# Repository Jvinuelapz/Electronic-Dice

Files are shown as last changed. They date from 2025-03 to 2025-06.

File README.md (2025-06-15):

# Electronic Dice with ATmega328P

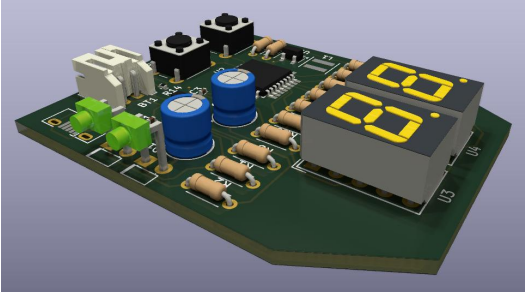
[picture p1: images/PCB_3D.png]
3D Visualization of the PCB Design


This repository documents a complete engineering design cycle for a multi-sided electronic dice. The project covers the entire development process, from initial problem definition and component research to detailed schematic design, PCB layout, software development, and 3D enclosure modeling. While a physical prototype was not assembled, all engineering stages for a production-ready device were completed.

The final design is a compact, key-fob-sized device featuring a rechargeable LiPo battery, USB-C charging, and a dual 7-segment display.

📄 **[Read the full project report (PDF)](Development%20Process.pdf)**

---

## ✨ Key Features

* **Multi-Sided Dice:** Supports d4, d6, d8, d10, d12, and d20 dice types, selectable via a tactile button.
* **Compact Design:** The final PCB measures just 38 x 48 mm.
* **Clear Display:** Utilizes two 7-segment displays with multiplexing to clearly show roll results.
* **Rechargeable:** Powered by a 150mAh LiPo battery with on-board USB charging via a TP4057 IC.
* **Power Management:** Includes an LM2731 step-up voltage regulator to provide a stable 5V supply to all components.

---

## ⚙️ The Engineering Process

This project followed a structured engineering lifecycle to ensure all objectives were met efficiently and reliably.

1. **Problem Definition:** Defined client requirements, project objectives, and created a Gantt chart for project planning.

2. **Research & Feasibility:** Analyzed existing products and sourced compatible, cost-effective components (ATmega328P, 7-segment displays, etc.). A full feasibility assessment (Technical, Economic, Operational) was conducted.

3. **Concept Design:**
   
    * **Software:** Developed the logic flow, including dice type selection, random number generation, and display multiplexing.
    * **Hardware:** Created a detailed schematic, outlining power management, microcontroller connections, and user interface components.

4. **PCB & Enclosure Design:**

    * Designed a compact, two-layer PCB using KiCad, optimized for size and signal integrity.
    * Modeled a custom 3D-printable enclosure in Autodesk Fusion 360 to house all components securely.

5. **Simulation & Validation:** The core logic was tested in a simulated breadboard environment to validate the software and hardware interaction before finalization.

---

# 🚀 Core Competencies

* **Embedded Systems Programming:** C++ development for the ATmega328P microcontroller using the Arduino IDE.
* **PCB Design & Layout:** Schematic capture and two-layer PCB design using KiCad.
* **Hardware Design:** Component selection, power management design (charging, voltage regulation), and circuit simulation.
* **3D Modeling:** Designing a functional and ergonomic enclosure for 3D printing using Autodesk Fusion 360.
* **Project Management:** Following a structured engineering design cycle from concept to a production-ready design.

---

# 🔧 Technical Specifications

* **Microcontroller:** ATmega328P-AU
* **Display:** 2x HDSP-513A Common Cathode 7-Segment Displays
* **Power:** 3.7V 150mAh LiPo Battery
* **Charging:** TP4057 Charging IC with Micro-USB input
* **Voltage Regulator:** LM2731 Step-Up Converter (outputting 5V)
* **User Input:** 2x Tactile Switches (for dice type and roll)

---

## 🗂️ Repository Structure

- `/code`: Contains the Arduino `.ino` sketch for the microcontroller.
- `/Hardware`: Includes the source files for the PCB layout (`/PCB`)and the 3D model for the enclosure (`/3D_Model`).
- `/Images`: Contains visual assets for this README.
- `Development_Process.pdf`: The detailed logbook documenting the entire project.

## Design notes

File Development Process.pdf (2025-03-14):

## Engineering Cycle, Mixed Signal Processing and PCB

## Design

Task 1: Define the problem statement

Firstly, read the background above and understand what the client wants you to develop.

List all the objectives related to the problem statement and develop a Gantt Chart to

show how long this project might take to complete.

Alex, a board game enthusiast, desires a compact device that can function as a multi-

sided dice generator. This device should meet the following key objectives:

- Compact size: No larger than 70mm x 50mm.
- Multi-dice Functionality: Dice types d4, d6, d8, d10, d12 and d20.
- Visual display: Reveals the result of each roll.
- True randomness
- User-friendly interface: A button to switch between dice types.
- Extended battery life

Based on the objectives, here’s a Gantt Chart for the estimated timeline of the project.

Activity | Week 1 | Week 2 | Week 3
Define the problem statement
Research and analysis
Brainstorming
Concept Development – Hardware
Concept Development – Software
Feasibility Assessment
Detailed Design and Planning – Schematic Design Detailed Design and Planning – PCB Design Detailed Design and Planning – Material and Resource Planning

Field Ready Prototype and Testing and Evaluation Optimization and Improvement
Design a 3D model case for the product
Table 1. Electronic Dice Project's Gantt Chart

Task 2: Research and analysis

Look at existing products and approved sellers to find which parts you need to make this client project. Make an Equipment table that follows this structure, please add more columns if needed.

For this task, I focused on identifying the components needed to design and build the product. I researched existing products and suppliers to find parts that met the project requirements, considering cost, availability, and compatibility. The goal was to ensure the components are efficient, compact, and aligned with the client's needs.

Component Research and Justification

The table below summarizes the key components I considered initially and the rationale

behind their selection:

Supplier and Cost Overview

I sourced the components from approved suppliers like Mouser Electronics, Digi-Key,

and Model Rockets to ensure high quality and reliability. The table below shows the

details of the selected components, including cost, quantity, and manufacturer. Here are

key observations from the initial list of components needed.

Table 2. Initially Needed Components List

1. Total Cost

The total cost of the main components is approximately £18, including VAT but not

including shipping, which fits within a reasonable budget for prototyping.

2. Suppliers and Reliability

Most components were sourced from Mouser Electronics, with the battery sourced

from Model Rockets. All suppliers are reputable, ensuring reliable components and

availability.

3. Compatibility

All components are compatible with the 3.3V–5V operating range of the system. For

example, the LiPo battery and step-up voltage regulator ensure that the

microcontroller and display receive stable power.

Observations and Challenges

- Component Size: The compact size of components like the ATMEGA328P-AU

and the 7-segment display ensures that the project can meet the size constraint.

Product NameProduct Description URL | Distributor | Manufacturer Cost (inv VAT)Quantity | | | Total
ATMEGA328P-AU8-bit Microcontrollers - MCU 32KB In-system Flash 20MHz 1.8V-5.5V https://www.mouser.co.uk/ProductDetail/Microchip-Technology/ATMEGA328P-AU?qs=K8BHR703ZXiCmmgp6%2FGNmQ%3D%3D Mouser Electronics Mrochip | | | £2.10 | 1 | £2.10
7-segment (HDSP-513A) LED Displays & Accessories Red 643nm 0.56in 7 Segment https://www.mouser.co.uk/ProductDetail/Broadcom-Avago/HDSP-513A?qs=pQfy5%252BKCabIcw5BGtxIW9w%3D%3D Mouser Electronics Broadcom Limited | | | £1.55 | 2 | £3.10
Tactile Switch (PHAP3344R) Tactile Switches TACT SWITCH PCB MOUNT https://www.mouser.co.uk/ProductDetail/Apem/PHAP3344R?qs=HFfMDpzxxd0eFvDypKImNg%3D%3D Mouser Electronics Apem | | | £0.32 | 2 | £0.64
Usb B Micro (USB3080-30-00-A) USB Connectors Micro B Skt, Bottom-SMT, R/A, 30u" NoPeg, W/shell stake, T&R https://www.mouser.co.uk/ProductDetail/GCT/USB3080-30-00-A?qs=KUoIvG%2F9IlZDMJJTQkXE0A%3D%3D Mouser Electronics GCT | | | £0.56 | 1 | £0.56
Lipo Battery (M105318) 3.7V 150mAh LiPo battery. https://modelrockets.co.uk/ground-equipment/batteries/150mah-3-7v-lipo-battery-2-pin-jst-connector/ Model RocketsPKCell | | | £8.75 | 1 | £8.75
Step-Up Voltage Regulator (LM2731YMF) Switching Voltage Regulators 0.6/1.6 MHz Boost Converters With 22V Internal FET Switch in SOT-23 5-SOT-23 -40 to 125 https://www.mouser.co.uk/ProductDetail/Texas-Instruments/LM2731YMF?qs=X1J7HmVL2ZEEUACYDb9YJg%3D%3D Mouser Electronics Texas Instruments | | | £3.02 | 1 | £3.02

- Power Efficiency: I selected a LiPo battery from Model Rockets and a voltage

regulator to optimize the dice for extended use, ensuring low power consumption,

while the system is portable.

- Cost vs. Quality: While some cheaper alternatives were available, I prioritized

components with a proven track record to avoid issues during prototyping.

Task 3: Brainstorming

For the microcontroller, there were a few options on the table. Initially, we thought about

using an Arduino UNO, given its familiarity and ease of use. However, its size was a

drawback for this project. We also considered the ATtiny85, which is compact but has

only 3 pins, limiting the number of components it could support. The ATtiny84 offered

more pins (12), but we felt it still might be too restrictive for the design’s complexity.

Finally, we chose the ATmega328P, a small and compact device, yet it offers enough

I/O pins to handle all the necessary components without compromising functionality.

Next, we discussed the power supply. Since the device needs to be portable, we quickly

dismissed the idea of using a standard 9V battery, which would be bulky and require

frequent replacements. Instead, we opted for a rechargeable LiPo battery. To make

recharging easy, we decided to integrate a USB-B micro connector for charging,

ensuring that the device could be conveniently powered up without needing external

chargers or frequent battery replacements.

For the display, the main challenge was finding something that would clearly show the

numbers without consuming too much power or requiring too many pins. Initially, we

investigated using an OLED or e-ink display, but these would require more complex

programming and higher power consumption than necessary. We settled on two 7-

segment displays because we could use multiplexing, which would allow us to control

both displays with fewer pins, further optimizing the design.

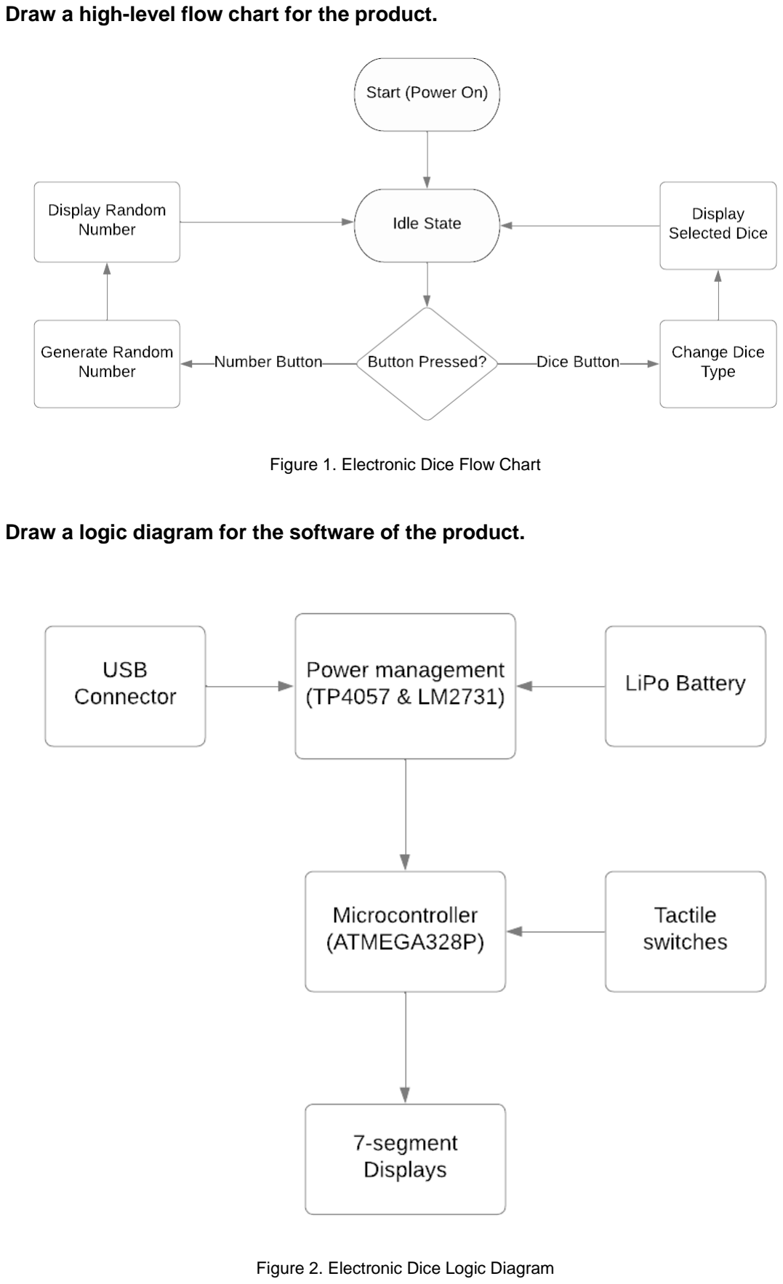
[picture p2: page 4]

Draw a high-level flow chart for the product.

Figure 1. Electronic Dice Flow Chart

Draw a logic diagram for the software of the product.

Figure 2. Electronic Dice Logic Diagram

Task 4: Concept Development – Hardware

The initial hardware prototype for the project involves using an Arduino UNO, which

incorporates the ATmega328P microcontroller, along with two buttons and two 7-

segment displays to visualize the results. The system simulates a dice rolling mechanism

with multiple dice types (d4, d6, d8, d10, d12, and d20). Here's a breakdown of how the

hardware is connected:

- Buttons: The first button is used to switch between different dice types (d4, d6,

etc.). Each press cycles through the different dice options and shows on the

display the selected dice. The second button is responsible for generating a

random number within the selected dice range.

- 7-Segment Displays: The output is visualized on two 7-segment displays, which

are used to show the dice result. The segments (A-G) of both 7-segment displays

are wired together to the same GPIO pins of the ATmega328P.

The cathodes of the two displays are connected to separate GPIO pins on the

microcontroller. This allows for multiplexing, where each display can be controlled

individually by activating its corresponding cathode while turning off the other display.

This way, we can display different numbers on each display despite sharing the segment

connections.

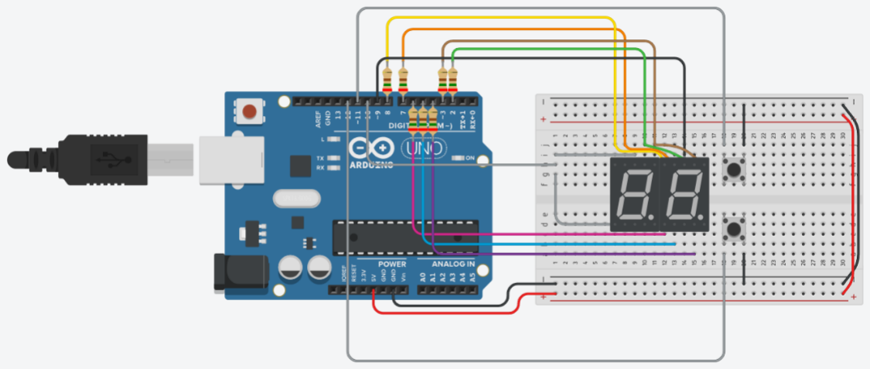
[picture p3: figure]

Figure 3. Electronic Dice Hardware Concept

Task 5: Concept Development – Software

Once the main hardware concept was outlined, including the microcontroller, buttons,

and displays, the next step was to integrate the corresponding software. The software is

tightly coupled with the hardware, ensuring that all components work seamlessly

together to achieve the intended functionality. The code controls the dice rolling system, manages user inputs, and displays the results in real time on two 7-segment displays.

Here’s a breakdown of the code and how it functions:

1. Pin Assignments:
- Pins pinA through pinG control the segments of the 7-segment display

(common across both displays).

- display1Pin and display2Pin are used for multiplexing between the two

displays, allowing each digit to be shown one at a time.

- buttonDiceType is for selecting the type of dice, and buttonRoll triggers the

roll to generate a new random number.

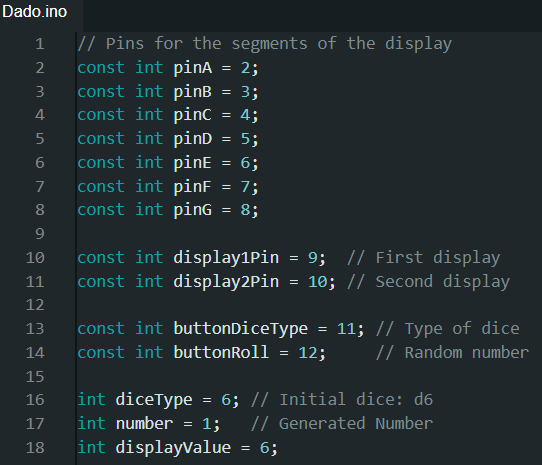
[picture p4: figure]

Figure 4. Electronic Dice Initialization

2. Initial Variables and Constants:
- diceType starts at 6, representing a d6 dice by default.
- displayValue stores the number currently displayed on the displays.
- digitSegments array holds the binary encoding for each digit to control which

segments are turned on for each number.

3. Setup Function:
- Configures segment pins and display control pins as outputs.
- Sets up buttons with INPUT_PULLUP mode, enabling internal pull-up

resistors.

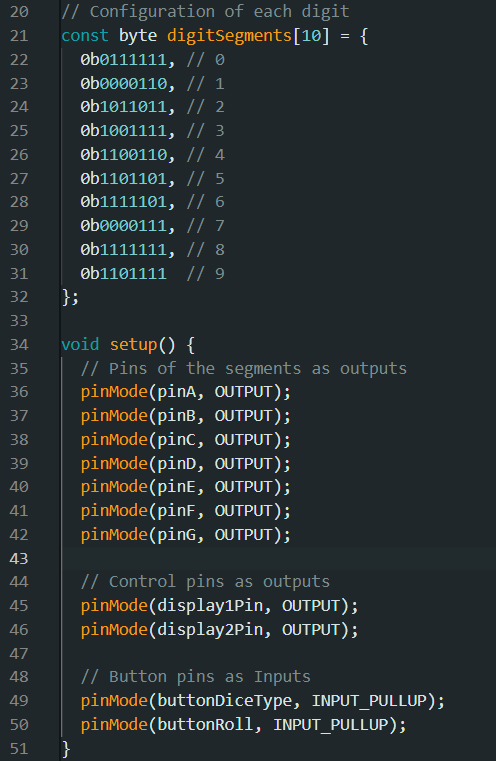
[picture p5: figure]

Figure 5. Electronic Dice Setup Function

4. Loop Function:
- When buttonDiceType is pressed, it calls changeDiceType function to cycle

through different dice types (d4, d6, d8, d10, d12, and d20).

- When buttonRoll is pressed, it calls rollDice function to generate a random

number within the current dice range.

- After handling button inputs, the displayNumber(displayValue); function is

called to show the current number on the 7-segment displays with

multiplexing.

5. Dice Type Switching (changeDiceType):
- It cycles through the dice types in this order: d4 → d6 → d8 → d10 → d12 →

d20, then back to d4.

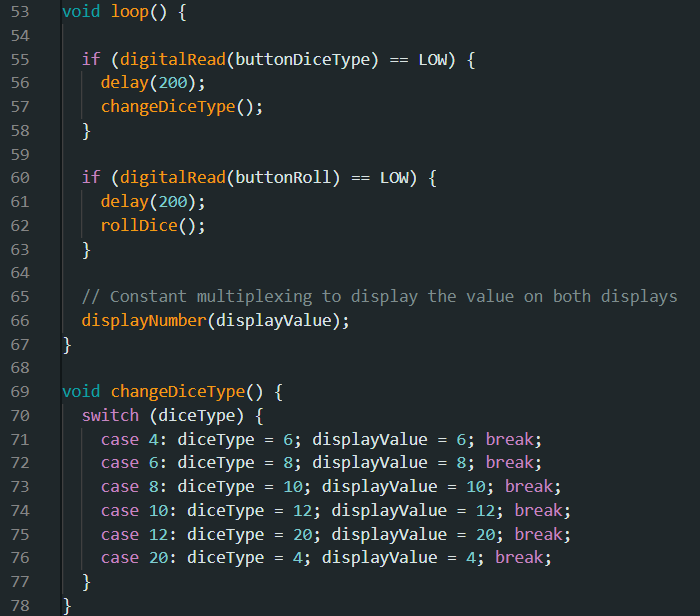
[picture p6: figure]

Figure 6. Electronic Dice Loop Function

6. Dice Rolling (rollDice):
- It generates a random number between 1 and the maximum value of the

selected dice type and stores it on the DisplayValue variable.

7. Displaying the Number (displayNumber):
- This function splits the number into tens and units.
- Each digit is displayed on its respective display using multiplexing, with a brief

delay to switch between digits smoothly.

8. Setting Segments (setSegments):
- This function uses bitwise operations to activate the correct segments for a

given digit by controlling each segment pin.

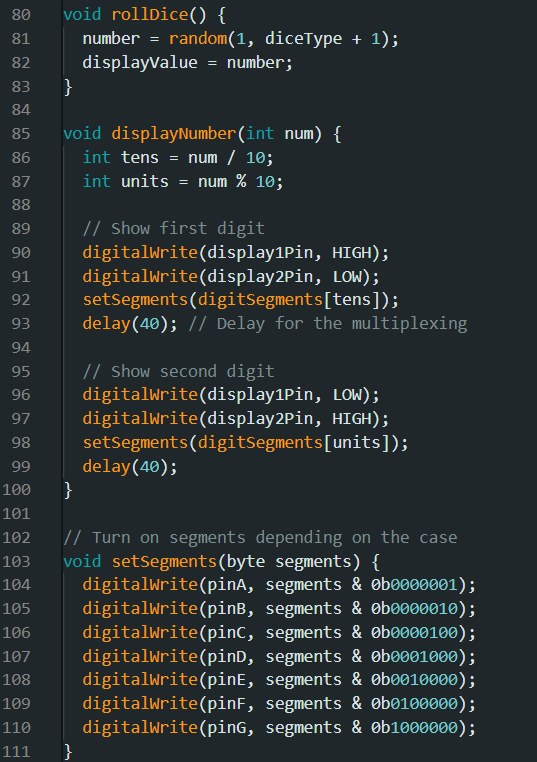
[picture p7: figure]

Figure 7. Electronic Dice RollDice Function

Task 6: Feasibility Assessment

In this task, I evaluated the technical, economic, and operational feasibility of the product

design, by analysing the finalized component selection, costs, and compatibility. This

way, I ensured that the design aligns with the project’s constraints and objectives.

Below is the finalized table of components, including their descriptions, suppliers, costs,

and quantities:

Table 3. Final List of Components

Technical Feasibility

The selected components meet the design’s technical requirements and are compatible

with each other to achieve the functionality of the product. Below is a detailed analysis

of how each component contributes to the system:

1. Core Components
- Microcontroller (ATMEGA328P-AU): It provides sufficient GPIOs to control

the two displays and reads inputs from the tactile buttons, while it supports

low-power operation.

- 7-segment displays (HDSP-513A): The use of two of these components

creates a compact two-digit display for showing dice roll results clearly.

Efficient power consumption and compatible with the regulated 5V supply.

2. Input Components
- Tactile Switches (PHA3344R): Two buttons necessary, one for cycling

through dice types and one for generating the random number. I selected

Single Pole Single Throw (SPST) switches, which ensure reliable user input

with robust tactile feedback.

3. Power Management Components
- LiPo Battery (3.7V, 150mAh): Compact and lightweight battery chosen

mainly to meet the device’s portability requirements, while providing sufficient

capacity for prolonged usage, powering the microcontroller, displays and

peripheral components. Additionally, the selected battery includes a built-in

security circuit, ensuring it never truly powers off, thus protecting the device

from abrupt power loss and preserving system stability during usage.

Product Name | Product Description URL | Distributor | Manufacturer | Cost (inv VAT) Quantity | | Total
ATMEGA328P-AU | 8-bit Microcontrollers - MCU 32KB In-system Flash 20MHz 1.8V-5.5V https://www.mouser.co.uk/ProductDetail/Microchip-Technology/ATMEGA328P-AU?qs=K8BHR703ZXiCmmgp6%2FGNmQ%3D%3D Mouser Electronics | | Microchip | £2.10 | 1 | £2.10
7-segment (HDSP-513A) | LED Displays & Accessories Red 643nm 0.56in 7 Segment https://www.mouser.co.uk/ProductDetail/Broadcom-Avago/HDSP-513A?qs=pQfy5%252BKCabIcw5BGtxIW9w%3D%3D Mouser Electronics | | Broadcom Limited | £1.55 | 2 | £3.10
250R Resistor (OK15G5E-R52) | Carbon Film Resistors - Through Hole 1.5 Ohm 1/4W 5% 250 Volt https://www.mouser.co.uk/ProductDetail/Ohmite/OK15G5E-R52?qs=AkUtuiJmyfmB5P4Zp1aBYw%3D%3D Mouser Electronics | | Ohmite | £0.09 | 7 | £0.63
Tactile Switch (PHAP3344R) | Tactile Switches TACT SWITCH PCB MOUNT https://www.mouser.co.uk/ProductDetail/Apem/PHAP3344R?qs=HFfMDpzxxd0eFvDypKImNg%3D%3D Mouser Electronics | | Apem | £0.32 | 2 | £0.64
TP4057 | SOT23-6 BATTERY MANAGEMENT ICS R https://www.digikey.co.uk/en/products/detail/umw/TP4057/17635237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 DigiKey | | UMW | £0.42 | 1 | £0.42
Usb B Micro (USB3080-30-00-A)USB Connectors Micro B Skt, Bottom-SMT, R/A, 30u" NoPeg, W/shell stake, T&R https://www.mouser.co.uk/ProductDetail/GCT/USB3080-30-00-A?qs=KUoIvG%2F9IlZDMJJTQkXE0A%3D%3D Mouser Electronics | | | GCT | £0.56 | 1 | £0.56
JST-PH 2 Pin Connector (B2B-PH-K-S) CONN HEADER VERT 2POS 2MM https://digikey.co.uk/en/products/detail/jst-sales-america-inc./B2B-PH-K-S/926611?productid=926611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 DigiKey | | | JST Sales America Inc. | £0.16 | 1 | £0.16
Led Charging (TLPR5600) | LED RED DIFF SIDE VIEW T/H R/A https://www.digikey.co.uk/en/products/detail/vishay-semiconductor-opto-division/TLPR5600/4074661 DigiKey | | Vishay Semiconductor Opto Division£0.60 | | 1 | £0.60
Led Charged (TLPG5600) | LED GREEN DIFF SIDE VIEW T/H R/A https://www.digikey.co.uk/en/products/detail/vishay-semiconductor-opto-division/TLPG5600/4074658 DigiKey | | Vishay Semiconductor Opto Division£0.60 | | 1 | £0.60
Ceramic Capacitor (CL05B103JB5NNND) CAP CER 0.1UF 50V X7R 0402 https://www.digikey.co.uk/en/products/detail/samsung-electro-mechanics/cl05b103jb5nnnd/3894195 DigiKey | | | Samsung Electro-Mechanics | £0.10 | 2 | £0.20
Electrolitic Capacitor (865080642006) CAP ALUM 10UF 20% 50V SMD https://www.digikey.co.uk/en/products/detail/w%C3%BCrth-elektronik/865080642006/5728046 DigiKey | | | Würth Elektronik | £0.18 | 2 | £0.36
1k Resistor (CF1/2CT52R102J) | RES 1K OHM 5% 1/2W AXIAL https://www.digikey.co.uk/en/products/detail/koa-speer-electronics-inc/cf1-2ct52r102j/13537515 DigiKey | | KOA Speer Electronics, Inc. | £0.11 | 2 | £0.22
2k Resistor (CF1/4CT52R202J) | RES 2K OHM 5% 1/4W AXIAL https://www.digikey.co.uk/en/products/detail/koa-speer-electronics-inc/cf1-4ct52r202j/13537624 DigiKey | | KOA Speer Electronics, Inc. | £0.09 | 2 | £0.18
Lipo Battery (M105318) | 3.7V 150mAh LiPo battery. https://modelrockets.co.uk/ground-equipment/batteries/150mah-3-7v-lipo-battery-2-pin-jst-connector/ Model Rockets | | PKCell | £8.75 | 1 | £8.75
Step-Up Voltage Regulator (LM2731YMF) Switching Voltage Regulators 0.6/1.6 MHz Boost Converters With 22V Internal FET Switch in SOT-23 5-SOT-23 -40 to 125 https://www.mouser.co.uk/ProductDetail/Texas-Instruments/LM2731YMF?qs=X1J7HmVL2ZEEUACYDb9YJg%3D%3D Mouser Electronics | | | Texas Instruments | £3.02 | 1 | £3.02
1.2k Resistor (CFM12JT1K20) | RES 1.2K OHM 5% 1/2W AXIAL https://www.digikey.co.uk/en/products/detail/stackpole-electronics-inc/CFM12JT1K20/1741836 DigiKey | | Stackpole Electronics Inc | £0.08 | 1 | £0.08
3.9k Resistor (CF14JT3K90) | RES 3.9K OHM 5% 1/4W AXIAL https://www.digikey.co.uk/en/products/detail/stackpole-electronics-inc/CF14JT3K90/1741386 DigiKey | | Stackpole Electronics Inc | £0.08 | 1 | £0.08
SMD Power inductor (SRR1210-100M) Power Inductors - SMD 10uH 20% SMD 1210 https://www.mouser.co.uk/ProductDetail/Bourns/SRR1210-100M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 Mouser Electronics | | | Bourns | £0.96 | 1 | £0.96
10k Resistor (MCT0603MD1052BP500) Thin Film Resistors - SMD MCT 0603-25 0.1% AT P5 10K5 https://www.mouser.co.uk/ProductDetail/Vishay-Beyschlag/MCT0603MD1052BP500?qs=17u8i%2FzlE883pCG3RQV5%2Fw%3D%3D Mouser Electronics | | | Vishay / Beyschlag | £0.34 | 2 | £0.68
| | | | | Total | £23.34

- Step-Up Voltage Regulator (LM2731YMF): Boosts the 3.7V output of the

battery to 5V, ensuring stable voltage for all the components in the product,

while it efficiently regulates power to avoid unnecessary losses and extending

battery life.

- Battery Charging IC (TP4057): Allows recharging the LiPo battery via a

micro-USB connector, ensuring safe charging with built-in overcharge

protection.

- Capacitors
- Ceramic Capacitors (0.1µF): Used for decoupling to stabilize voltage

and filter noise in the power supply, ensuring smooth operation of the

microcontroller and display.

- Electrolytic Capacitors (10µF): Provide additional power stability,

particularly for the voltage regulator during periods of higher current

draw.

4. Passive Components
- 250Ω Resistors: Current-limiting resistors for the 7-segment displays,

ensuring that LEDs are not overdriven.

- 1kΩ and 3.9kΩ Resistors: Pulldown or pullup resistors for tactile switches to

ensure stable signal readings from the buttons.

5. Connectivity Components
- Micro-USB Connector: Robust and compact design that allows the device

to be charged conveniently using standard USB power sources,

- JST Connector: Provides secure and compact connections for the battery,

making assembly and maintenance easier.

6. Additional Considerations
- Multiplexing for 7-segment Displays: By multiplexing (the microcontroller

alternates between the tens and units digits quickly enough to make it appear

as though both digits are displayed at the same time) the two displays, I

successfully reduced the number of GPIO pins needed to control the

segments.

- Size Constraints: The use of compact components such us the

microcontroller or the battery fit in the key-fob-sized requirements.

Additionally, SMD versions of passive components further minimize the

overall PCB size.

The selected components are expected to operate seamlessly together under the

specified voltage conditions (5V, which preventing flickering or glitches). With this

efficient power management, the device is projected to offer extended usage on single

charge while maintaining functionality.

Economic Feasibility

This assessment is evaluated based on the total cost of components, sourcing reliability,

production scalability, and the cost-benefit considerations of design decisions. Below is

an in-depth analysis of the cost and financial implications of the project:

1. Component Cost Analysis
- The total cost of components, including VAT, is £22.63 for a single unit. This

cost is reasonable for a prototyping phase where parts are sourced

individually and not in bulk (Shipping not included).

2. Bulk Production Potential
- Savings in Bulk Orders: Many components can be purchased at

significantly reduced prices when ordered in bulk, like passive components or

microcontrollers. A rough estimate shows that bulk purchasing could

decrease the component cost per unit by 20-30%, bringing the cost closer to

£16 per unit in a hypothetical larger scale production.

- Scalability: By transitioning to Surface Mount Devices (SMD) for passive

components, assembly time and labour costs can be reduced in large scale

manufacturing. A single PCB design can accommodate all components for

automated assembly, which lowers production costs.

- Value vs. Cost: In the prototype stage, £22.63 per unit is justified by the need

for high-quality components to ensure functionality during testing. Moreover,

the ability to recharge the device adds value to the design, avoiding the

recurring cost of disposable batteries. On the other hand, for a retail product

it would be essential to find cost reduction strategies to achieve a profitable

margin while keeping the final product affordable.

3. Challenges
- Initial Cost for Prototyping: Prototyping often incurs higher costs due to the

lack of economies of scale.

- Logistics: The need to source the components from multiple suppliers

increases the shipping costs and complexity. Consolidating suppliers or

sourcing locally could benefit the overall cost

4. Future Cost Optimization
- Component Consolidation: Explore integrated IC solutions that combine

microcontroller, power management, and charging capabilities to reduce the

total component count and cost.

- Supplier Negotiations: Negotiate with suppliers for better pricing when

ordering in bulk.

The project is economically feasible for prototyping and offers significant potential for

cost reduction in bulk production. By balancing quality, functionality, and affordability, the

design ensures a competitive product with a strong value proposition. Future cost

optimization strategies will further enhance its viability for commercial production.

Operational Feasibility

The operational feasibility of the product focuses on the ease of assembly, user

functionality, portability, and maintainability. Below is a detailed analysis of how the

design meets these operational objectives:

1. Ease of Assembly
- Component Placement: The use of through-hole components, like the tactile

switches and resistors, simplifies prototyping and assembly during the initial

design stage. However, for larger scale production it would be necessary to

transition to SMD components. A well-optimized PCB design ensures that

components are logically and efficiently placed, minimizing assembly errors.

- Modular Design: Critical parts, such as the battery or the USB connector,

are easily replaceable, which ensures straightforward repairs or upgrades if

needed. Additionally, the use of a JST connector allows for simple

disconnection and reconnection without soldering, if needed.

2. User Functionality
- Dice Rolling Process: The design provides a simple and intuitive interface

by using only two buttons, one for selecting the dice and the other for rolling

it. The user sees the both the selected dice and the generated number on the

7-segments displays, with multiplexing ensuring smooth digit transitions.

- Multi-Dice Compatibility: The device supports multiple dice types, as

required by the client, which increases the utility and appeal of the device.

- Portability: The compact design ensured the dice is lightweight and easy to

carry and the use of a rechargeable LiPo battery eliminates the need for disposable ones, making it more user-friendly and environmentally

sustainable.

- Display Clarity: The two displays provide bright and readable numbers even

in low-light conditions.

3. Power Efficiency
- Battery Life: The 3.7V 150mAh LiPo battery provides sufficient capacity for
extended | use, | especially | with | the | low-power | ATMEGA328P-AU

microcontroller. Efficient power management is achieved using the step-up

voltage regulator to provide a stable 5V output, ensuring all components

operate optimally without wasting energy.

- Charging Process: The TP4057 charging IC allows the device to be

conveniently recharged via a micro-USB port, ensuring ease of use and

minimizing downtime.

4. Maintainability
- Repairability: Key components like the LiPo battery and tactile switches are

modular and can be easily replaced in case of failure.

- Software Updates: The ATMEGA328P-AU can be reprogrammed via its ISP

(In-System Programming) interface, enabling software updates or bug fixes

without hardware changes.

- Component Durability: High-quality components ensure long-term

reliability.

5. Challenges and Risks
- Assembly Precision: Implementing multiplexing requires precise wiring and

logic to ensure functionality, given that errors during assembly could lead to

display glitches.

- Power Optimization: While the device is designed to efficient, real-world

testing is required to validate the expected battery life under usage patterns.

- Size Constraints: Assembling all components into the size requirements

while maintaining functionality and durability require careful PCB design and

component placement.

The design is operationally feasible, balancing ease of use, assembly simplicity, and

portability. While challenges such as size constraints and power efficiency require testing

and optimization, the design meets the project’s requirements and is well-suited for

prototyping and eventual production.

Task 7: Detailed Design and Planning – Schematic Design

The electronic dice circuit is designed to generate random dice rolls and display the

results on a dual 7-segment LED display. The design is divided into two main phases:

1. Power Management Phase: This phase handles the power input, battery

charging, and voltage regulation to ensure a stable 5V supply for the circuit. It

includes a micro-USB input, TP4057 battery charging IC, and LM2731 step-up

voltage regulator.

2. Control and Display Phase: This phase consists of the ATMEGA328P

microcontroller, tactile switches, and two 7-segment displays. The microcontroller

handles user inputs from the switches to select dice types and roll numbers. It

also manages the multiplexing and control of the 7-segment displays, ensuring

the rolled number is clearly shown to the user.

Power Management Phase

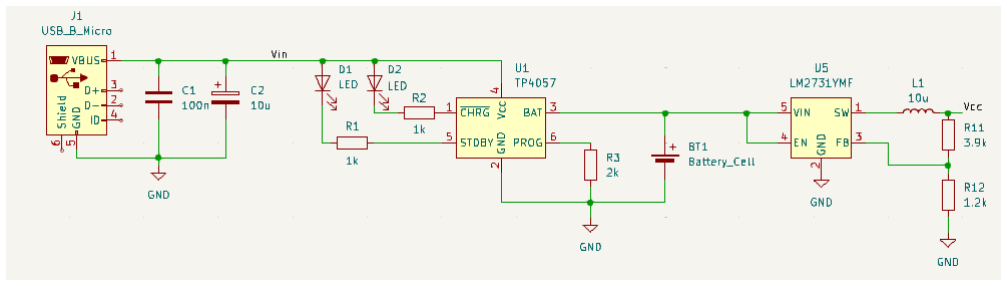
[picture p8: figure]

Figure 8. Power Management Phase Electric Scheme

In this section, the connections of each component in this phase will be explained in

detail.

1. Power Input (USB Connector)
- Component: J1 (USB_B_Micro):
- This connector provides power input to the system via a micro-USB

port.

- Pin 1 (VBUS): The power pin receives 5V from a standard USB

source.

- Pin 5 (GND): The ground connection.
- Capacitors:
- These are decoupling capacitors placed close to the USB connector

to stabilize the input voltage and filter out noise.

- C1 (100nF) handles high-frequency noise, while C2 (10µF) smooths

out low-frequency fluctuations.

2. Battery Charger TP4057 and Battery Cell
- Charger IC: TP4057 (U1):
- The TP4057 is a lithium-ion battery charging IC that ensures safe and

efficient charging of the connected battery cell.

- Pin 1 (CHRG): Connects to LED D1, which indicates charging status.
- Pin 2 (STDBY): Connects to LED D2, which indicates when the

charging is complete.

- Pin 3 (PROG): Connected to resistor R3 (2kΩ), which sets the

charging current, of approximately 500mA.

- Pin 5 (BAT): Connected to the positive terminal of the battery.
- Pin 6 (VIN): Receives the stabilized 5V from the USB input (Vin).
- Pin 4 (GND): Ground connection for the charger circuit.
- Battery Cell (BT1): A 3.7V lithium-ion battery is connected at this point,

charged by the TP4057.

3. Voltage Regulator
- Voltage Regulator IC: LM2731YMF (U5):
- This step-up voltage regulator increases the battery’s 3.7V to a stable

5V output for the rest of the circuit.

- Pin 5 (VIN): Accepts input voltage from the battery.
- Pin 1 (EN): Enable pin is tied to VIN, ensuring the regulator is always

on when the battery is connected.

- Pin 3 (FB): Feedback pin connected to a resistor divider (R11 and

R12) to set the output voltage, of 5V.

- Pin 2 (SW): The switching output is connected to an inductor (L1) to

boost the voltage.

Control and Display Phase

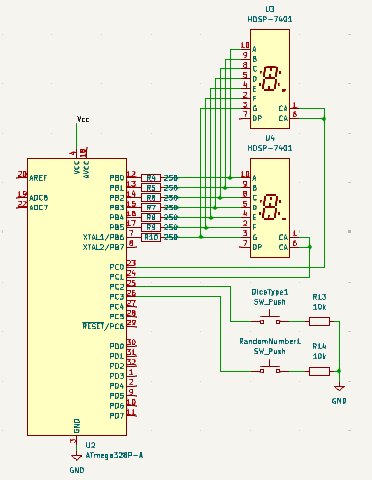
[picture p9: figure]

Figure 9. Control and Display Electric Scheme

In this section, the connections of each component in this phase will be explained in

detail.

1. Microcontroller: ATMEGA328P (U2)
- Power Supply:

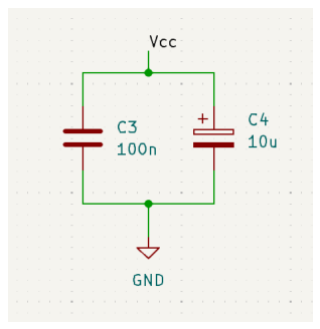
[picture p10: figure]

Figure 10. ATMEGA328P Power Supply

- Connected to Vcc with decoupling capacitors (C3 and C4) to stabilize

the power supply and filter noise.

- The ground pin (GND) is connected to the circuit's common ground.
- Connections:
- PB0–PB6 (Pins 12–18): Control the segments (A–G) of the two 7-

segment displays.

- PC0–PC1 (Pins 23, 24): Are used to multiplex the displays by

activating the common cathode of each display (U3, U4) alternately.

- PC2–PC3 (Pins 25, 26): Connected to the tactile switches for user

input.

2. Tactile Switches
- Dice Type Selection:
- Connected to PC2 of the microcontroller.
- Dice Roll Switch:
- Connected to PC3 of the microcontroller.
- Pull-Down Resistors:
- Each switch is connected to ground through pull-down resistors (R13

and R14).

3. 7-Segment Displays (U3, U4)
- Display Type:
- Common cathode displays are used for showing two-digit dice roll

results.

- Segment Control (Pins A–G):
- Each segment is connected to a GPIO pin of the microcontroller

(PB0–PB6) through current-limiting resistors (R4–R10, 250Ω each).

Task 8: Detailed Design and Planning – PCB Design

The project has reached the PCB design stage, with a finalized layout that integrates all

components and adheres to the project's compact size constraints. The PCB measures

38x48 mm, fitting the key-fob size requirement, while ensuring functionality, durability,

and manufacturability.

Final PCB (All Layers)

The image below represents the completed PCB design, showing all layers and

components. It includes:

- Front copper traces connecting components.
- Back copper traces for signal routing and ground planes.
- Placement of all components such as the microcontroller, resistors, capacitors,

LEDs, switches, and 7-segment displays.

This view provides a complete picture of how the circuit is routed, ensures optimal space

utilization within the small dimensions, and remarks the dimensions of the PCB.

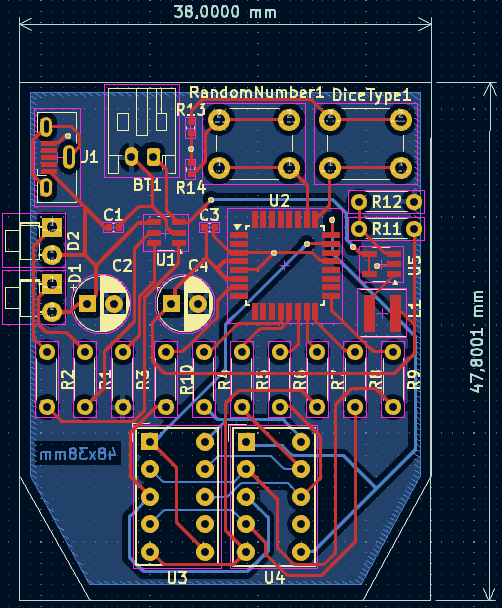
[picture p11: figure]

Figure 11. Electronic Dice PCB

Front Copper Layer

The second image highlights only the front copper layer, where most connections and

signal routing occur. This layer focuses on:

- Power distribution from the battery and voltage regulator to components.
- Critical signal traces connecting the microcontroller to the 7-segment displays

and switches.

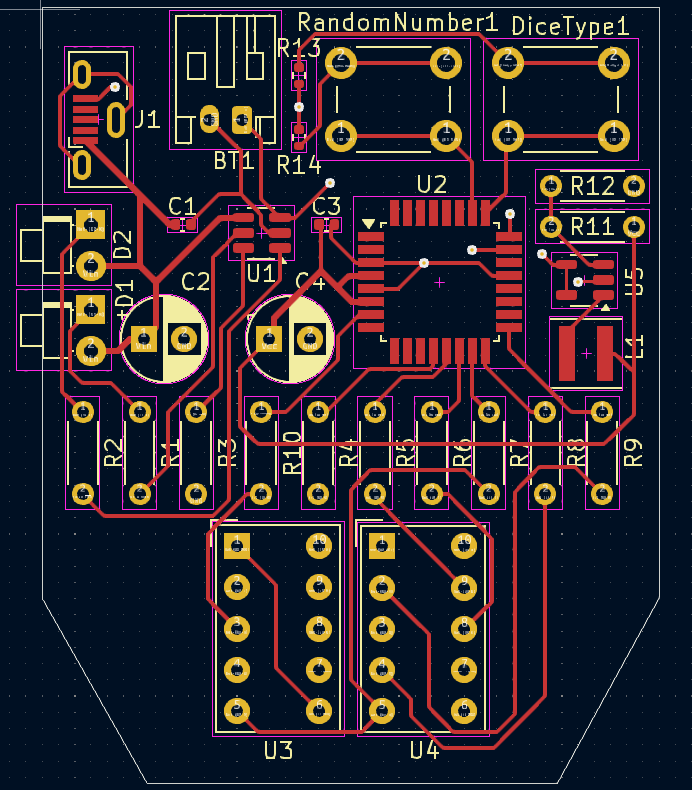
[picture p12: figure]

Figure 12. Front Copper Layer

Back Copper Layer

The third image isolates the back copper layer, primarily used for:

- Ground planes to reduce noise and stabilize the circuit.
- Supporting additional routing where space on the front layer is insufficient.

The inclusion of a back copper layer ensures a balanced and reliable PCB design, even

with compact dimensions.

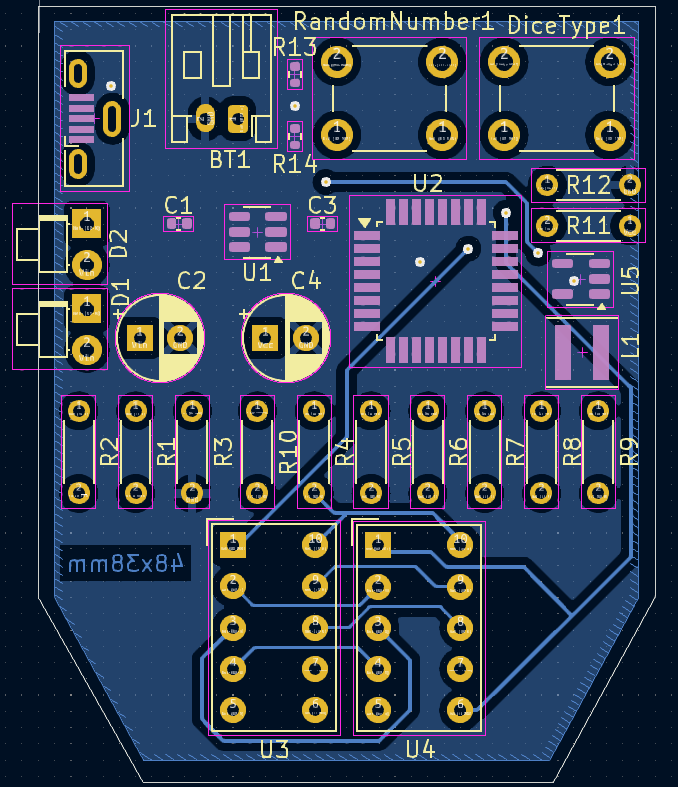
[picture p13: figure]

Figure 13. Back Copper Layer

3D View

The fourth image provides a 3D rendering of the assembled PCB, showcasing the layout

and physical placement of components. Key features include:

- Two 7-segment displays prominently positioned for clear visibility.
- Tactile switches for user input, aligned at the top for ergonomic access.
- Microcontroller and other passive components efficiently placed to minimize trace

lengths.

This visualization confirms the design's practicality and highlights the compact

arrangement within the 38x48 mm footprint.

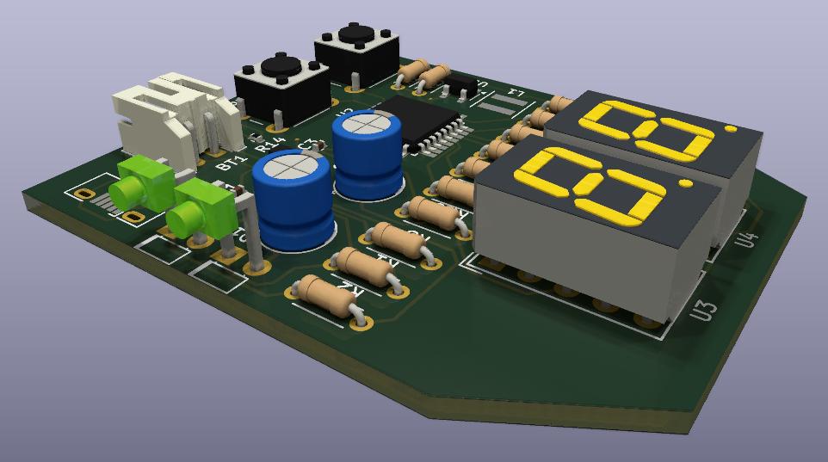
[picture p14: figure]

Figure 14. Electronic Dice PCB's 3D View

Task 9: Detailed Design and Planning – Material and Resource Planning

Using the approved seller's list from Task 2, I verified the availability of all components

required for the electronic dice PCB design. Below is the finalized Bill of Materials (BoM),

including each component's description, quantity, supplier, and total cost.
Product Name | Product Description | Distributor | Manufacturer | Cost (inc. VAT) | Quantity | Total
ATMEGA328P-AU | 8-bit Microcontrollers -MCU 32KB In-system Flash 20MHz 1.8V-5.5V | Mouser Electronics | Microchip | £2.10 | 1 | £2.10
7-segment (HDSP-513A) | LED Displays & Accessories Red 643nm 0.56in 7 Segment | Mouser Electronics | Broadcom Limited | £1.55 | 2 | £3.10
250R Resistor (OK15G5E-R52) | Carbon Film Resistors - Through Hole 1.5 Ohm 1/4W 5% 250 Volt | Mouser Electronics | Ohmite | £0.09 | 7 | £0.63
Tactile Switch (PHAP3344R) | Tactile Switches TACT SWITCH PCB MOUNT | Mouser Electronics | Apem | £0.32 | 2 | £0.64
TP4057 | SOT23-6 BATTERY MANAGEMENT ICS R | DigiKey | UMW | £0.42 | 1 | £0.42
Usb B Micro (USB3080-30-00-A) | USB Connectors Micro B Skt, Bottom-SMT, R/A, 30u" NoPeg, W/shell stake, T&R | Mouser Electronics | GCT | £0.56 | 1 | £0.56
JST-PH 2 Pin Connector (B2B-PH-K-S) | CONN HEADER VERT 2POS 2MM | DigiKey | JST Sales America Inc. | £0.16 | 1 | £0.16
Led Charging (TLPR5600) | LED RED DIFF SIDE VIEW T/H R/A | DigiKey | Vishay Semiconductor Opto Division | £0.60 | 1 | £0.60
Led Charged (TLPG5600) | LED GREEN DIFF SIDE VIEW T/H R/A | DigiKey | Vishay Semiconductor Opto Division | £0.60 | 1 | £0.60
Ceramic Capacitor (CL05B103JB5NNND) | CAP CER 0.1UF 50V X7R 0402 | DigiKey | Samsung Electro-Mechanics | £0.10 | 2 | £0.20
Electrolytic Capacitor (865080642006) | CAP ALUM 10UF 20% 50V SMD | DigiKey | Würth Elektronik | £0.18 | 2 | £0.36
1k Resistor (CF1/2CT52R102J) | RES 1K OHM 5% 1/2W AXIAL | DigiKey | KOA Speer Electronics, Inc. | £0.11 | 2 | £0.22
2k Resistor (CF1/4CT52R202J) | RES 2K OHM 5% 1/4W AXIAL | DigiKey | KOA Speer Electronics, Inc. | £0.09 | 2 | £0.18
Lipo Battery (M105318) | 3.7V 150mAh LiPo battery. | Model Rockets | PKCell | £8.75 | 1 | £8.75
Step-Up Voltage Regulator (LM2731YMF) | Switching Voltage Regulators 0.6/1.6 MHz Boost Converters With 22V Internal FET Switch in SOT-23 5-SOT-23 -40 to 125 | Mouser Electronics | Texas Instruments | £3.02 | 1 | £3.02
1.2k Resistor (CFM12JT1K20) | RES 1.2K OHM 5% 1/2W AXIAL | DigiKey | Stackpole Electronics Inc | £0.08 | 1 | £0.08

3.9k Resistor (CF14JT3K90) | RES 3.9K OHM 5% 1/4W AXIAL | DigiKey | Stackpole Electronics Inc | £0.08 | 1 | £0.08
SMD Power inductor (SRR1210-100M) | Power Inductors -SMD 10uH 20% SMD 1210 | Mouser Electronics | Bourns | £0.96 | 1 | £0.96
10k Resistor (MCT0603MD1052BP500) | Thin Film Resistors -SMD MCT 0603-25 0.1% AT P5 10K5 | Mouser Electronics | Vishay / Beyschlag | £0.34 | 2 | £0.68
| | | | Total | £23.34

Table 4. Materials Needed

Observations

1. Suppliers:
- Most components are sourced from Mouser Electronics and DigiKey due to

their reliability and comprehensive selection.

- The LiPo battery was sourced from Model Rockets, a trusted supplier for

compact power sources.

2. Availability:
- All components are available and compatible with the PCB design. There is

no risk of delay due to unavailability.

3. Cost Efficiency:
- The total cost is reasonable for a functional prototype, staying within budget

constraints.

This finalized BoM ensures all necessary components are ready for assembly and

testing.

Task 10: Field Ready Prototype and Testing and Evaluation

In this task, I focused on testing the electronic dice system through a simulated

breadboard setup using software tools. This practical simulation allowed for evaluating

the functionality of key components, such as the buttons, random number generation,

and the display of results on the 7-segment displays. By conducting the tests in a

simulated environment, potential issues in the design were identified and resolved

without the need for a physical prototype. This simulation served as a crucial step in

validating the logic and performance of the circuit, ensuring that the system meets the

intended design requirements.

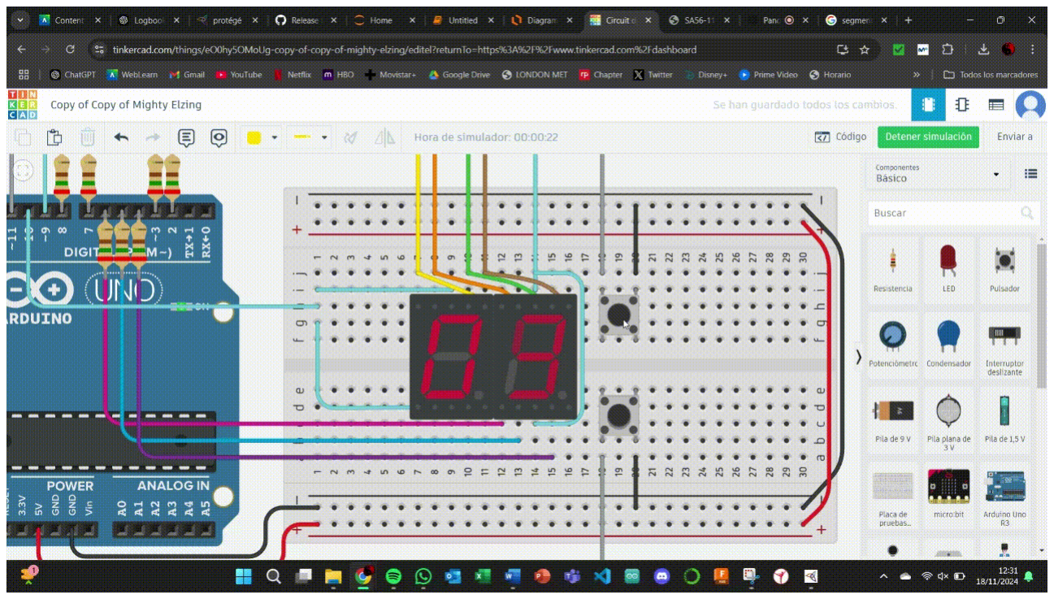
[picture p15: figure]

Figure 15. Field Ready Type Simulation

Task 11: Optimization and Improvement

The current design of the electronic dice meets the functional and size requirements, but

there are several areas where it can be improved to enhance efficiency, size, and

usability. Below are the proposed improvements:

Transition to SMD Components

One of the most effective ways to make the design smaller is by replacing through-hole

components with Surface Mount Devices (SMD).

- Using SMD resistors and capacitors can significantly reduce the PCB size.
- Smaller components result in shorter traces, which improves signal integrity and

reduces electromagnetic interference (EMI).

This change could potentially reduce the PCB dimensions below 38x48 mm, making the

design more compact and portable.

Implement Sleep Mode

Currently, no sleep mode has been implemented, meaning the device will consume

power continuously, even when idle. Adding a sleep mode could significantly improve

battery life:

1. How to Implement:
- Use the microcontroller’s built-in sleep features to enter a low-power state

when the device is inactive.

- Wake the microcontroller only when a button press is detected.

2. Benefits:
- Reduces power consumption during idle periods.
- Extends the battery life, making the dice more energy-efficient and practical

for long-term use.

Optimize Power Management

1. Current Design:
- The step-up regulator (LM2731) ensures a stable 5V output but introduces

inefficiency at low loads.

2. Proposed Improvement:
- Consider switching to a more efficient regulator with a power saving mode or

a buck-boost regulator to adapt to the varying load conditions of the dice.

- Add a power switch to manually disconnect the battery when not in use.

Improve Display Brightness Control

The 7-segment displays are always powered at full brightness, which might be

unnecessary in all lighting conditions.

- Implement PWM control for the displays to adjust brightness dynamically.
- Use a light-dependent resistor (LDR) to create an adaptive brightness feature

based on ambient light.

Add sound feedback

A small piezo buzzer could provide an audible click or tone when the dice is rolled,

improving the user experience.

Task 12: Design a 3D model case for the product

The case for the electronic dice has been designed with attention to detail to

accommodate all components, ensure portability, and maintain durability. Below, the

different perspectives of the design are analysed.

### 1. Initial view with only visible edges

This view highlights the basic shape and features of the case, including:

- Clean geometry with bevelled edges for a modern aesthetic.
- Two rectangular cutouts on the top for the dual 7-segment displays and the tactile

switches.

- A dedicated compartment to store the battery, which includes a removable cover

for easy access.

- Lateral holes for the USB connector, and the two LEDs.

- Legs so that the case can be standing on any plain surface.
- A compact design that prioritizes functionality while keeping the overall footprint

minimal.

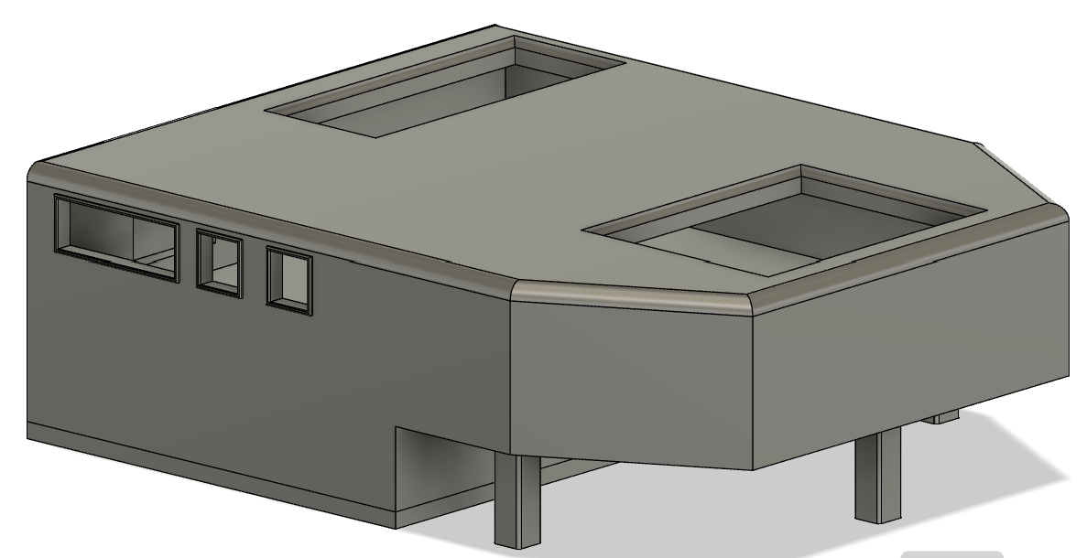
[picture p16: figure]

Figure 16. Electronic Dice's Case

### 2. Initial view with all edges

This transparent view allows the internal structure to be seen:

- Internal Component Layout: The positions of internal supports and mounting

structures for the PCB and components are clearly visible.

- Precision Cutouts: Openings for the USB port, tactile switches, and other

components are visible and aligned with their respective functionalities.

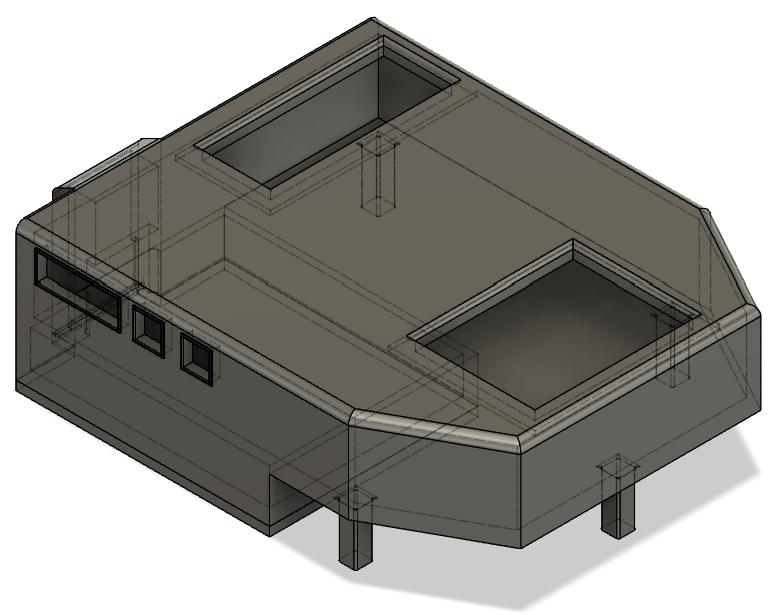
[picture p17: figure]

Figure 17. Case With All Edges Visible

### 3. Frontal view

The frontal view shows:

- The two cutouts for the 7-segment displays and the tactile switches, ensuring

they are flush with the surface for clear visibility.

- A smooth, symmetrical design that maintains simplicity and ease of use.

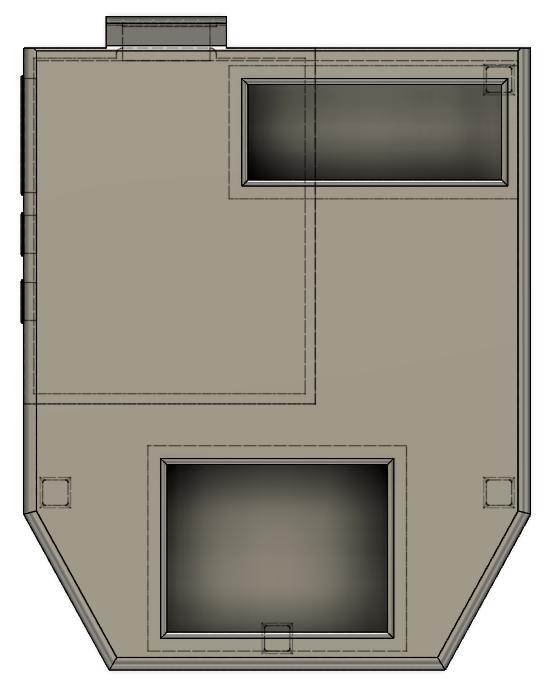
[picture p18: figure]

Figure 18. Frontal View

### 4. Top rear corner view

This perspective provides insight into:

- The angular design of the rear section, which accommodates the LiPo battery.
- Additional mounting posts and structural elements that reinforce the case for

durability and equilibrium.

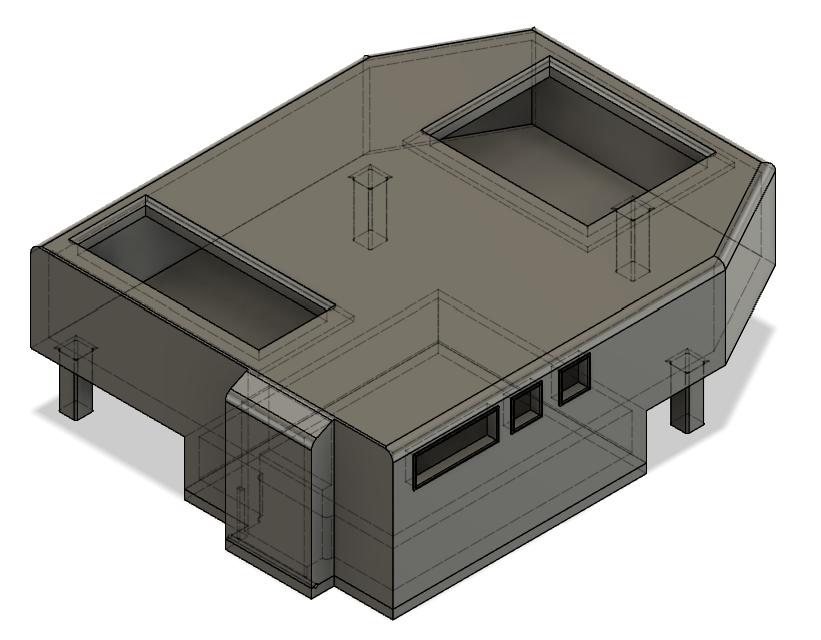
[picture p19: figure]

Figure 19. Top Rear Corner View

### 5. Top schematic with dimensions

This schematic provides precise measurements of the case:

- Overall Dimensions: The case measures 40.2 mm x 51.5 mm, ensuring it remains

compact and portable.

- Cutout Sizes: Detailed dimensions for the 7-segment display cutouts and side

openings show careful planning for component placement.

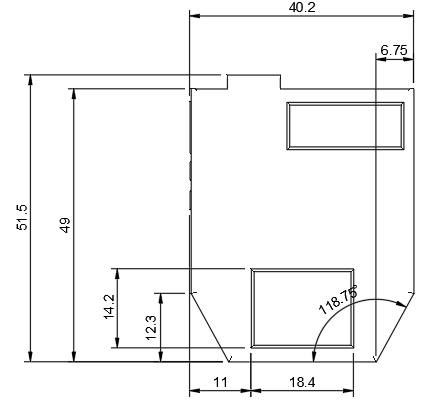
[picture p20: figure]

Figure 20. Top Schematic

### 6. Frontal and right-side schematic with dimensions

This view offers a detailed look at:

- The height of the case (16 mm), ensuring sufficient clearance for internal

components.

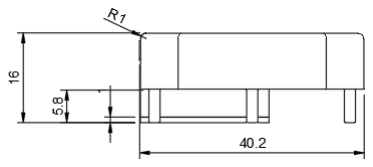
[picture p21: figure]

Figure 21. Frontal Scheme

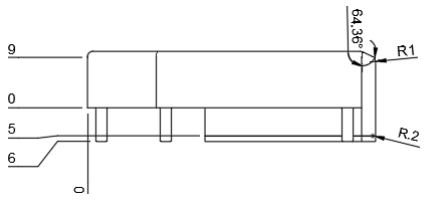
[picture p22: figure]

Figure 22. Right-Side Schematic

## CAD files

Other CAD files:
Hardware/Case_3DModel.f3d

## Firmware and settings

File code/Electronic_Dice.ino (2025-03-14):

// Pines para los segmentos del display
const int pinA = 2;
const int pinB = 3;
const int pinC = 4;
const int pinD = 5;
const int pinE = 6;
const int pinF = 7;
const int pinG = 8;

// Pines de control para cada display
const int display1Pin = 9;  // Control del primer display
const int display2Pin = 10; // Control del segundo display

// Pines de los botones
const int buttonDiceType = 11; // Botón para cambiar el tipo de dado
const int buttonRoll = 12;     // Botón para lanzar el dado

// Variables de estado
int diceType = 6; // Tipo de dado inicial: D6
int number = 1;   // Número generado
int displayValue = 6; // Valor a mostrar (tipo de dado o número generado)

// Mapeo de segmentos para cada dígito (0-9)
const byte digitSegments[10] = {
  0b0111111, // 0
  0b0000110, // 1
  0b1011011, // 2
  0b1001111, // 3
  0b1100110, // 4
  0b1101101, // 5
  0b1111101, // 6
  0b0000111, // 7
  0b1111111, // 8
  0b1101111  // 9
};

void setup() {
  // Configurar pines de segmentos como salidas
  pinMode(pinA, OUTPUT);
  pinMode(pinB, OUTPUT);
  pinMode(pinC, OUTPUT);
  pinMode(pinD, OUTPUT);
  pinMode(pinE, OUTPUT);
  pinMode(pinF, OUTPUT);
  pinMode(pinG, OUTPUT);
  
  // Configurar pines de control de displays como salidas
  pinMode(display1Pin, OUTPUT);
  pinMode(display2Pin, OUTPUT);

  // Configurar pines de botones como entradas con resistencia pull-up interna
  pinMode(buttonDiceType, INPUT_PULLUP);
  pinMode(buttonRoll, INPUT_PULLUP);
}

void loop() {
  // Cambiar el tipo de dado si se presiona el botón correspondiente
  if (digitalRead(buttonDiceType) == LOW) {
    delay(200); // Debounce
    changeDiceType();
  }

  // Generar un número aleatorio si se presiona el botón de lanzar
  if (digitalRead(buttonRoll) == LOW) {
    delay(200); // Debounce
    rollDice();
  }

  // Multiplexado constante para mostrar el valor en ambos displays
  displayNumber(displayValue);
}

// Función para cambiar el tipo de dado y mostrarlo en los displays
void changeDiceType() {
  switch (diceType) {
    case 4: diceType = 6; displayValue = 6; break;
    case 6: diceType = 8; displayValue = 8; break;
    case 8: diceType = 10; displayValue = 10; break;
    case 10: diceType = 12; displayValue = 12; break;
    case 12: diceType = 20; displayValue = 20; break;
    case 20: diceType = 4; displayValue = 4; break;
  }
}

// Función para generar el número aleatorio y mostrarlo
void rollDice() {
  number = random(1, diceType + 1);
  displayValue = number;
}

// Función para mostrar el número en ambos displays con multiplexado continuo
void displayNumber(int num) {
  int tens = num / 10;  // Dígito de las decenas
  int units = num % 10; // Dígito de las unidades

  // Mostrar decenas en el primer display
  digitalWrite(display1Pin, HIGH);
  digitalWrite(display2Pin, LOW);
  setSegments(digitSegments[tens]);
  delay(40); // Breve retardo para multiplexación

  // Mostrar unidades en el segundo display
  digitalWrite(display1Pin, LOW);
  digitalWrite(display2Pin, HIGH);
  setSegments(digitSegments[units]);
  delay(40); // Breve retardo para multiplexación
}

// Función para encender los segmentos según el patrón dado
void setSegments(byte segments) {
  digitalWrite(pinA, segments & 0b0000001);
  digitalWrite(pinB, segments & 0b0000010);
  digitalWrite(pinC, segments & 0b0000100);
  digitalWrite(pinD, segments & 0b0001000);
  digitalWrite(pinE, segments & 0b0010000);
  digitalWrite(pinF, segments & 0b0100000);
  digitalWrite(pinG, segments & 0b1000000);
}
